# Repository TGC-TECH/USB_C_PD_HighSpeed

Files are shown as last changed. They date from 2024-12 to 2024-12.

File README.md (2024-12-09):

# USB_C_PD_HighSpeed
High Speed USB C PD Hub

This was submitted for the ECSE Senior Project at CWRU 
It was designed by myself(Toby Cowles), Carter Graefnitz  & Zach Brown

You are welcome to modify the design with credit. 
Design Files are provided in Altium Designer 

Before ordering look at the technical report.pdf
The design should in theory work but is untested and has some minor clearence issues on U6 and C32
The design was designed for the JLC0616H-7628 stackup 

NO WARRENTY IS PROVIDED, THIS IS  FOR EDUCATIONAL AND REFERENCE PURPOSES ONLY!

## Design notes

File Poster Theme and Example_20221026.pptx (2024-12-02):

## High Speed High Power USB C PD Hub

Zach Brown (EE) Toby Cowles (EE,CE) Carter Graefnitz (EE)

Instructor/Advisor Dr.Gregory Lee, PhD, (ECSE Case Western Reverse University)

Problem, Background & Context:
There is not a commercial USB hub available that is capable of supplying high power USB C PD and high speed data (10Gb/s+) on the same hub. Therefore we propose the design and manufacture of such a hub.
Similar existing solutions are all flawed :
Commercial Solutions
-USB C Hubs (no power)
-USB PD adapters (no data)
-Thunderbolt Docks
(bulky, expensive, unneeded features, limited ports)
Existing Projects
https://github.com/Jana-Marie/PD-Injector
(Clunky, violates USB Spec, but provided assurance that something like this could be done)

System Architecture & Tech Constraints:
1. Limited IC selection. There are few 10gb/s USB hub ICs on the market and none faster Making custom ICs/working with non-public ICs is out of scope of this project so we will be constrained by what is available.
2. Routing traces and manufacturing boards for high frequency data gets more difficult the higher the data speed, which could limit the CMs we can work with as well as impose limits on the design tools required.
3. Troubleshooting data lines may be difficult given that it would require an oscilloscope fast enough to keep up with a 10 Gb/s data speed.

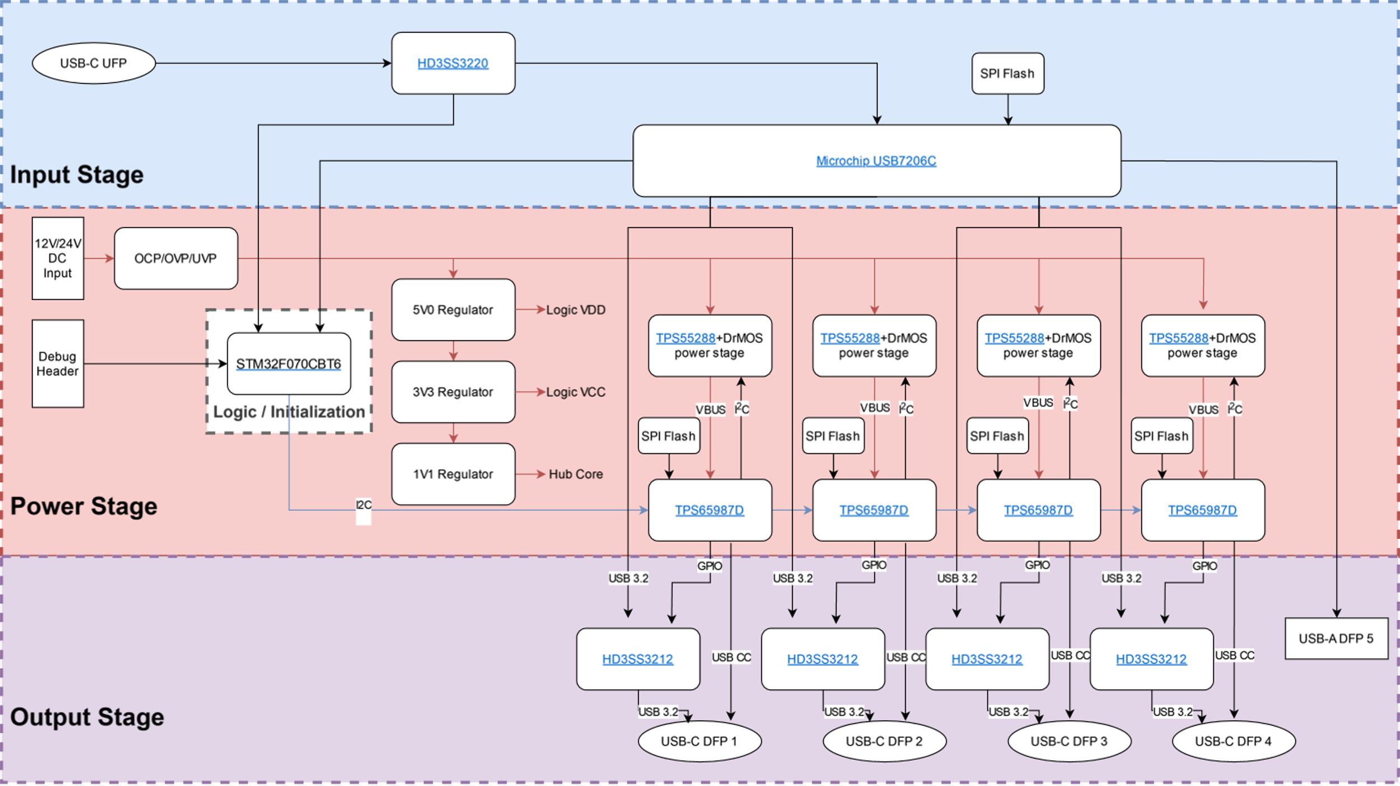
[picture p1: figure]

Schematic Capture:

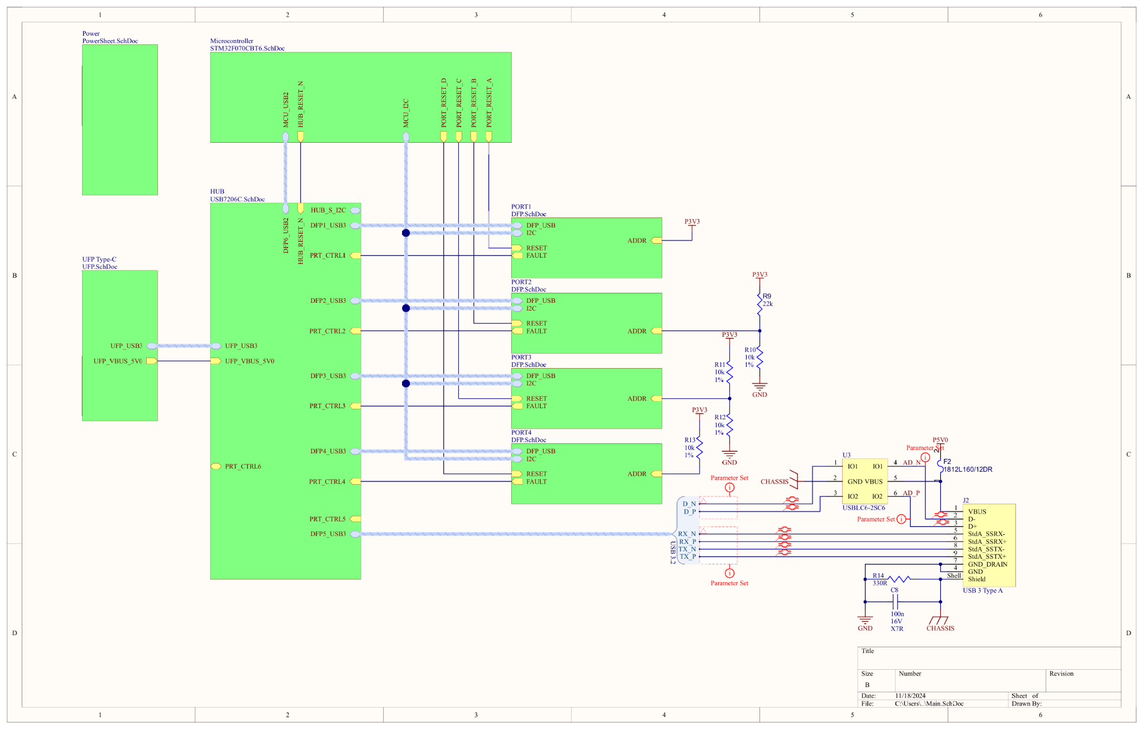
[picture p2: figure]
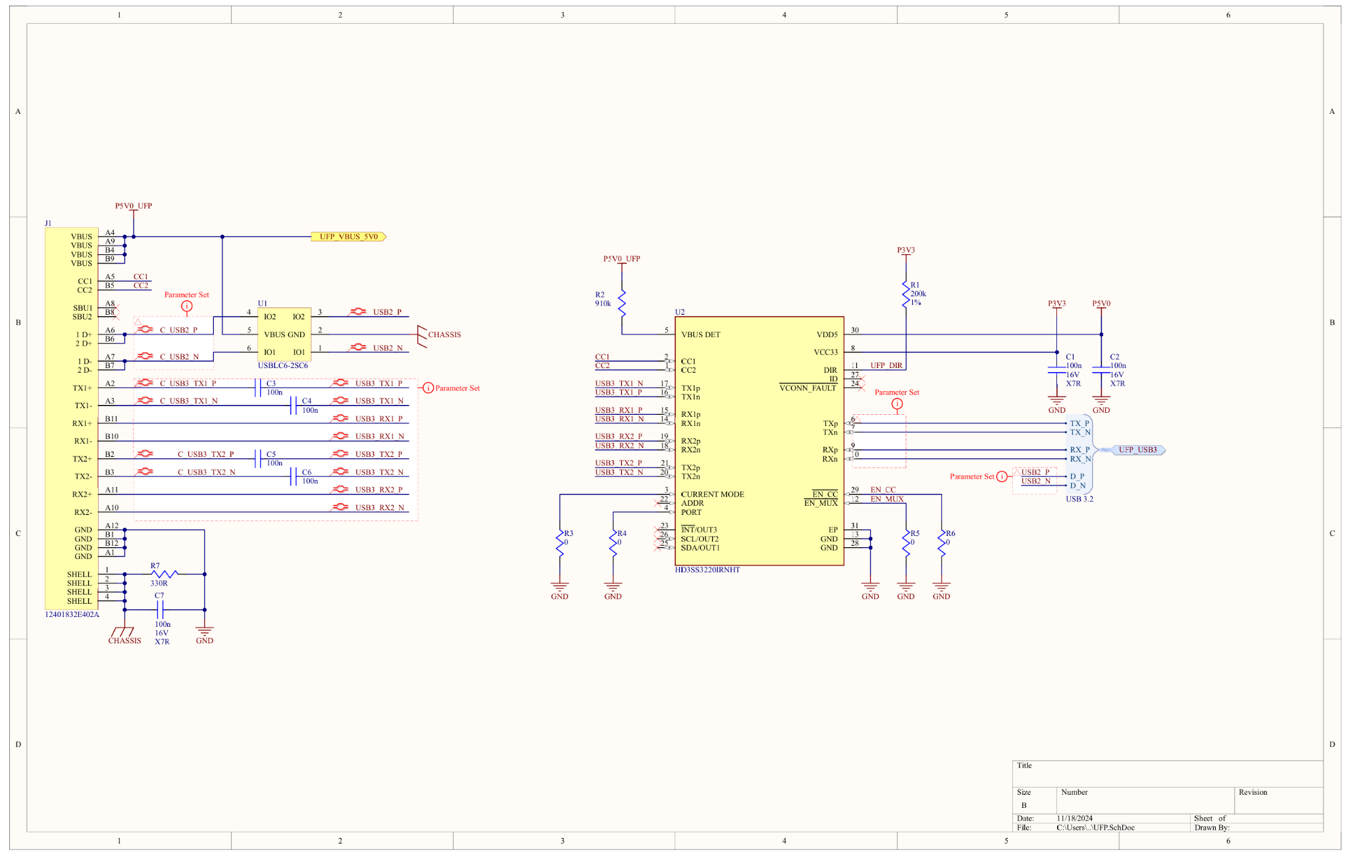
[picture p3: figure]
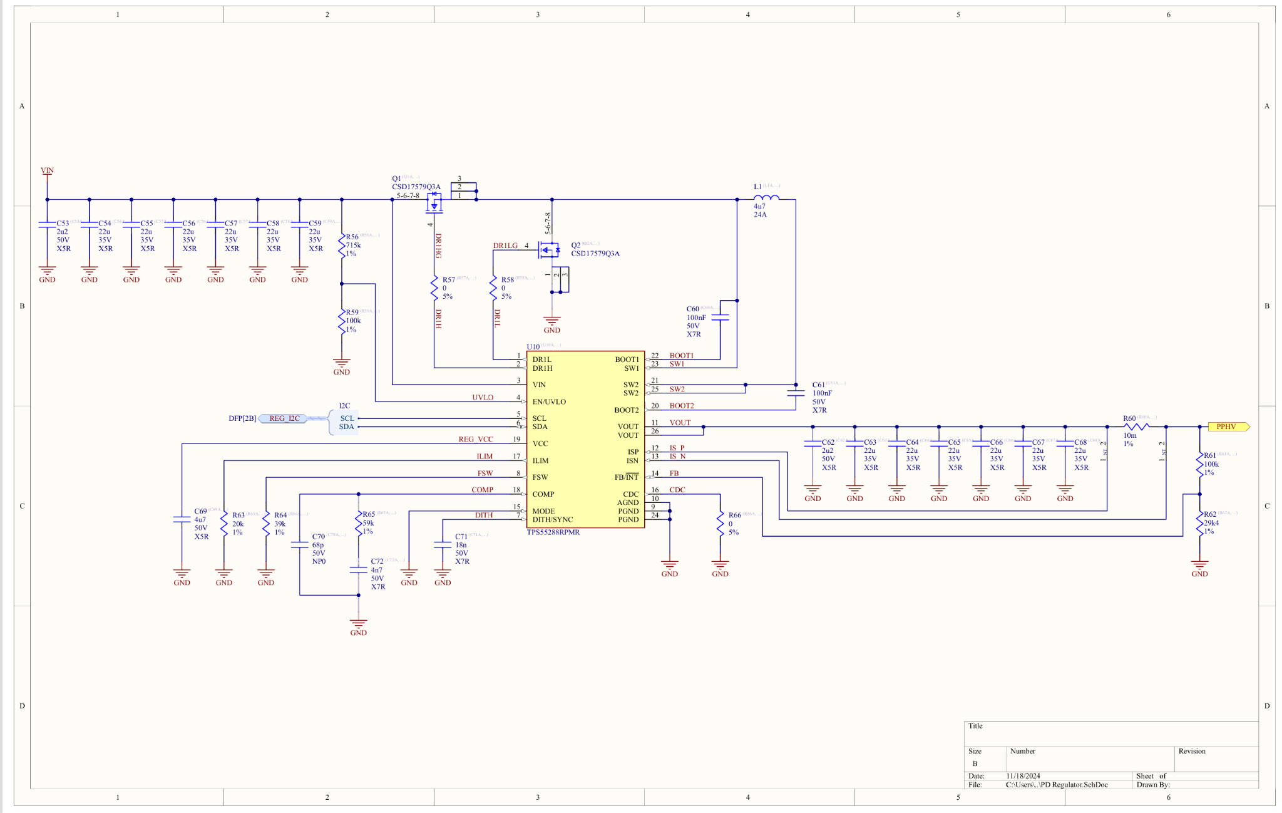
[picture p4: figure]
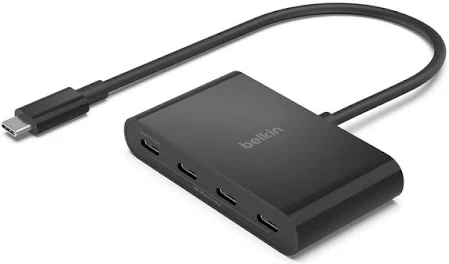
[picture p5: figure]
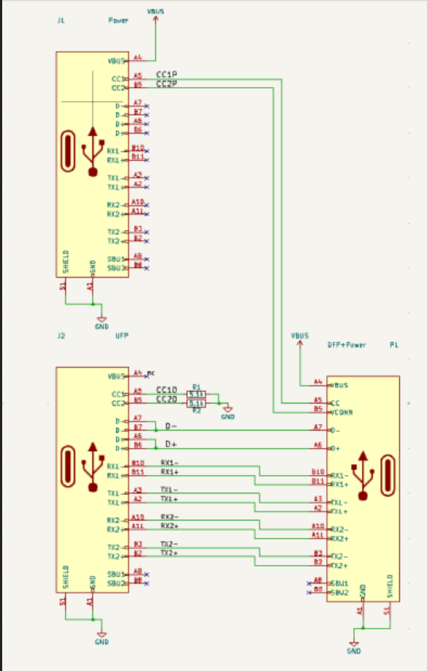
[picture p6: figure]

Jana Marie (github.com)

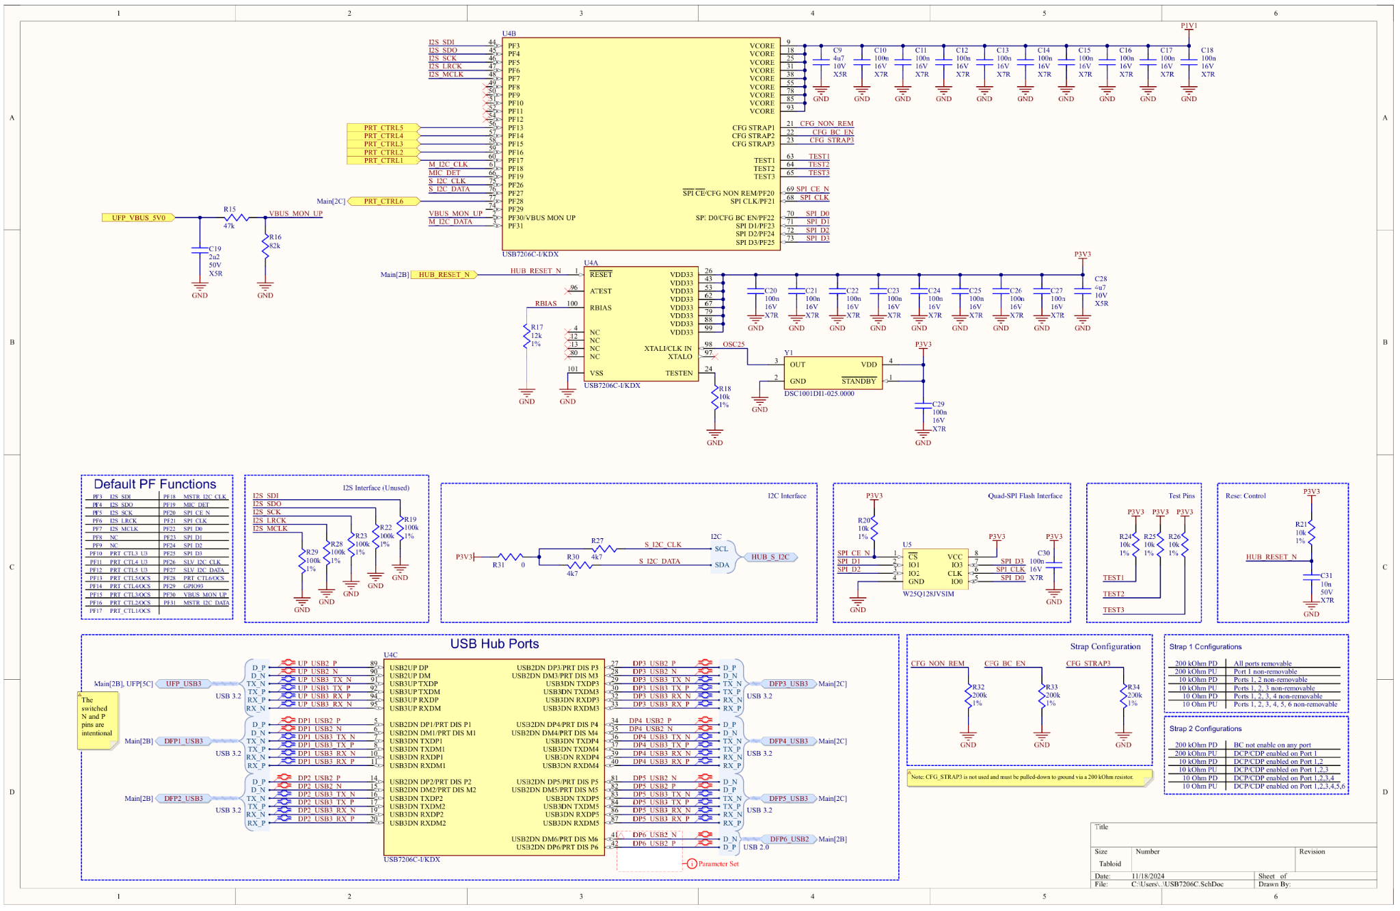
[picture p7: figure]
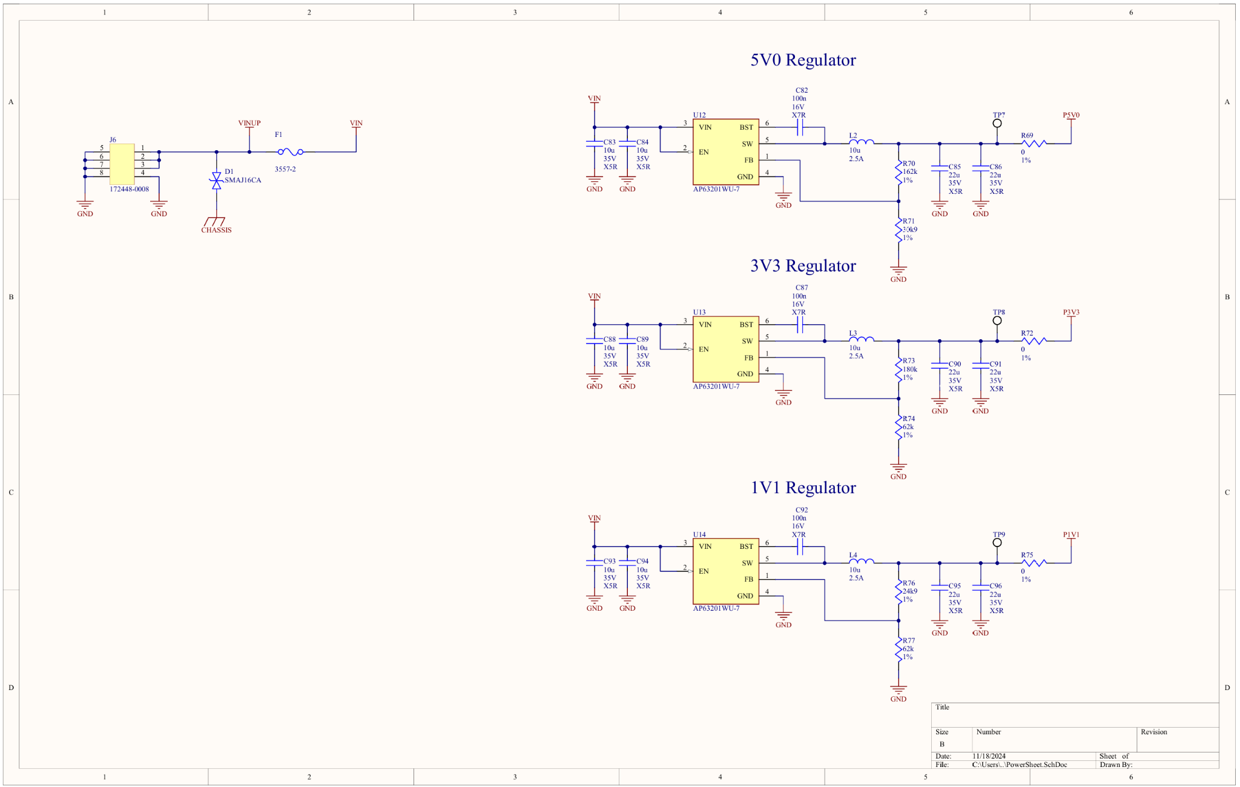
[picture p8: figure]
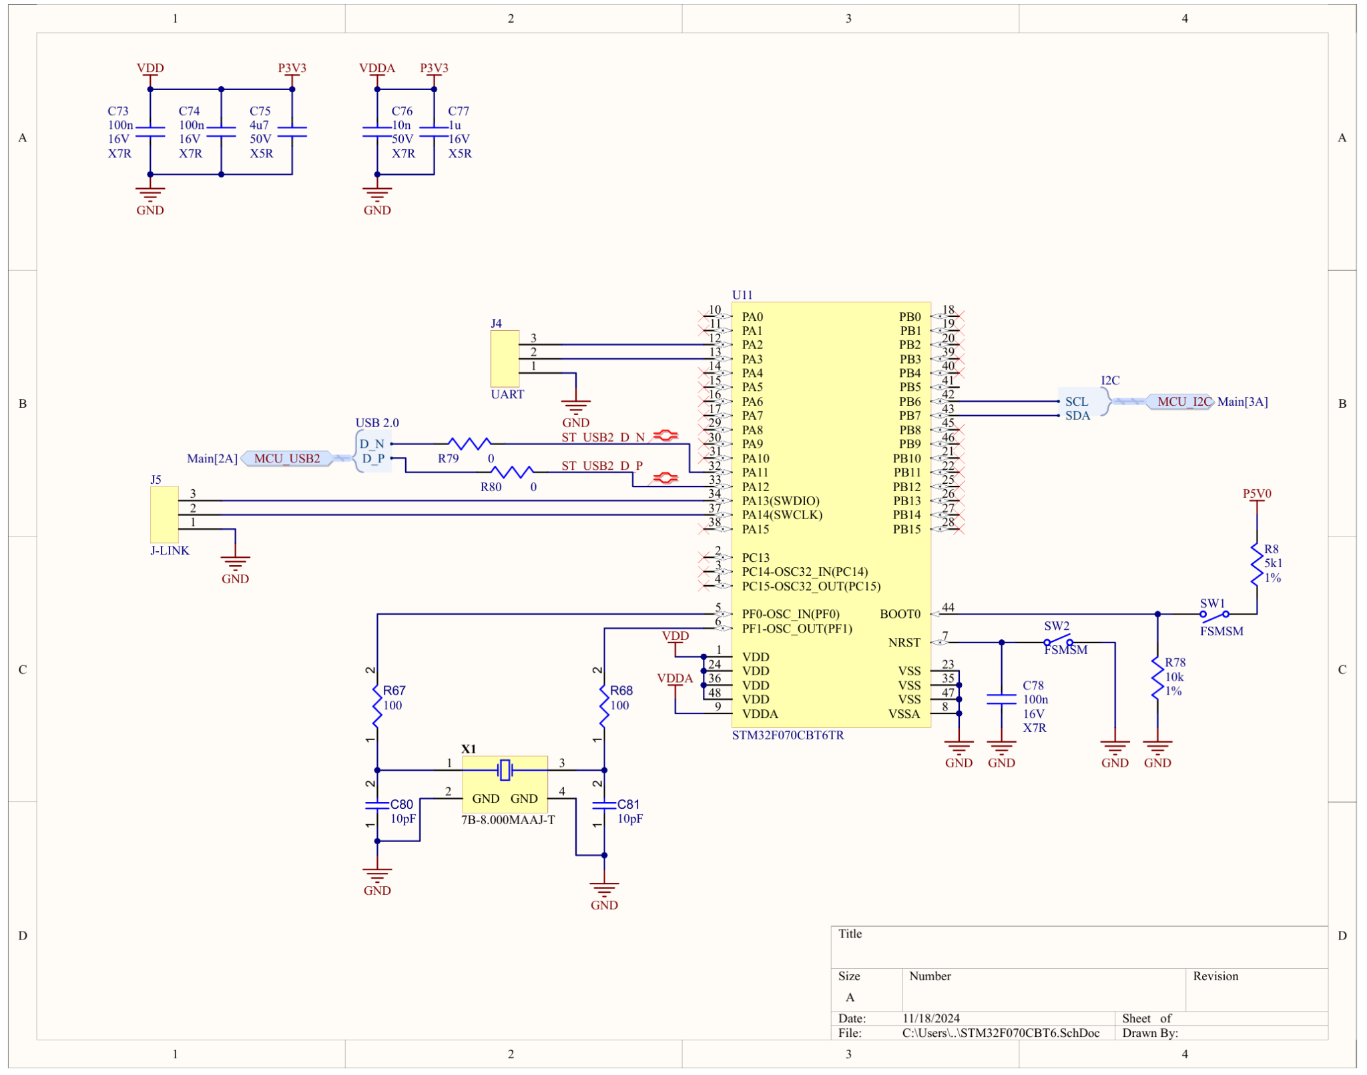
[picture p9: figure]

Schematic Capture was completed in Altium Designer.
We used a multi-sheet layout and sheet symbols to make the project efficient

Belkin.com

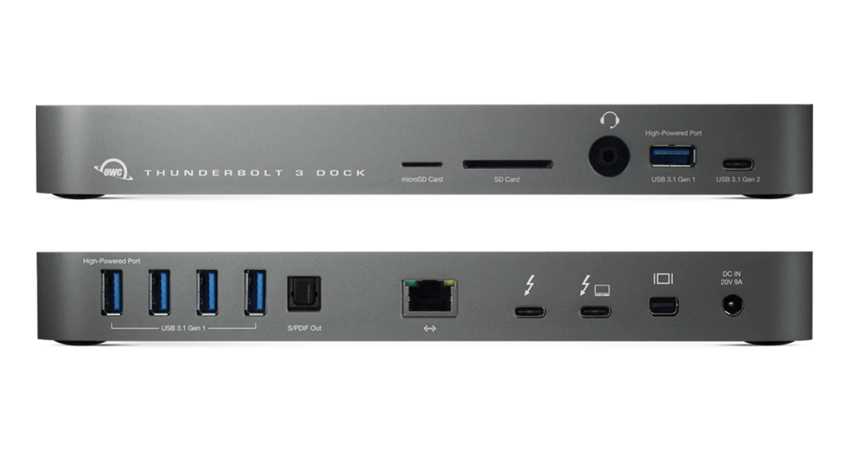
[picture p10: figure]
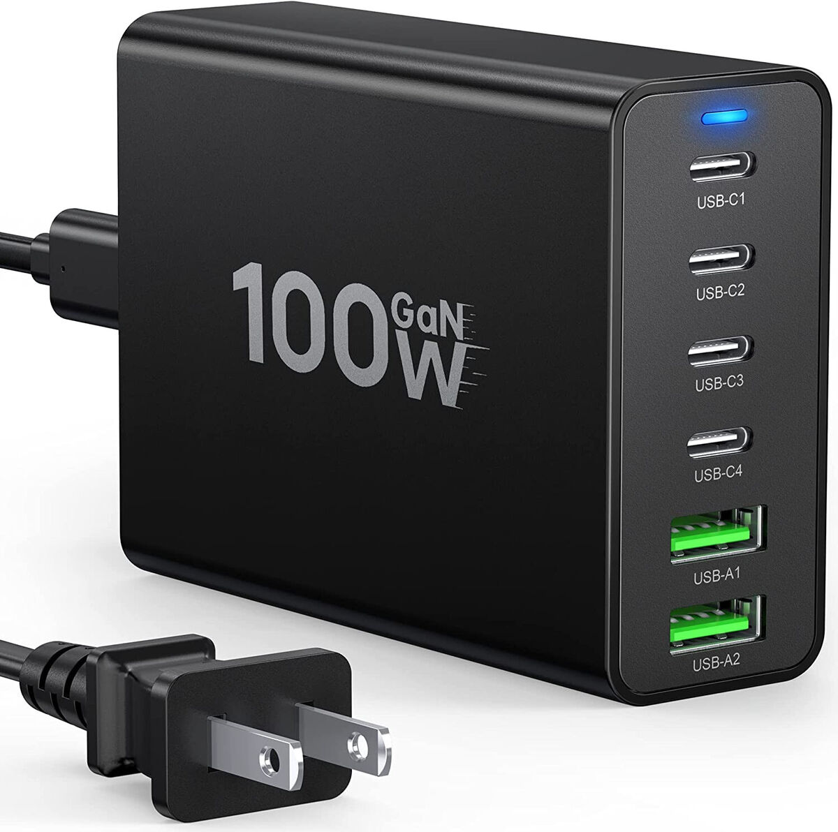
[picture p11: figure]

Amazon.com

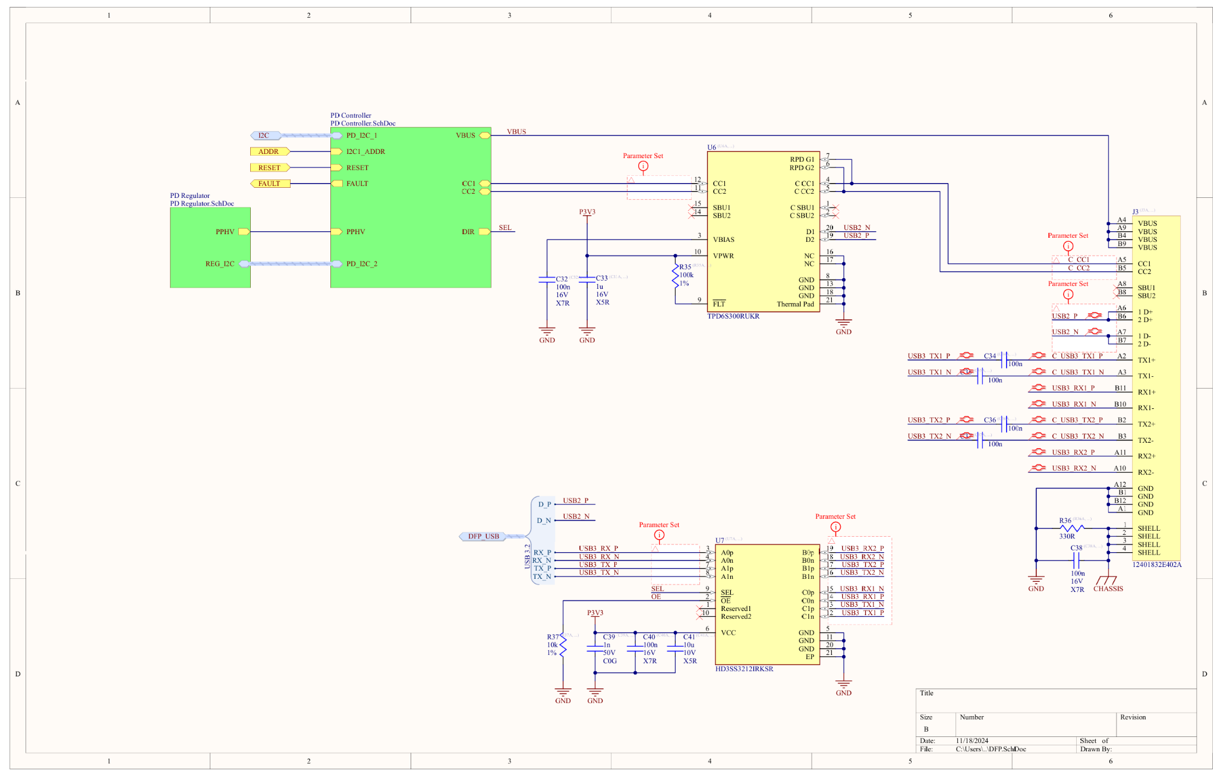
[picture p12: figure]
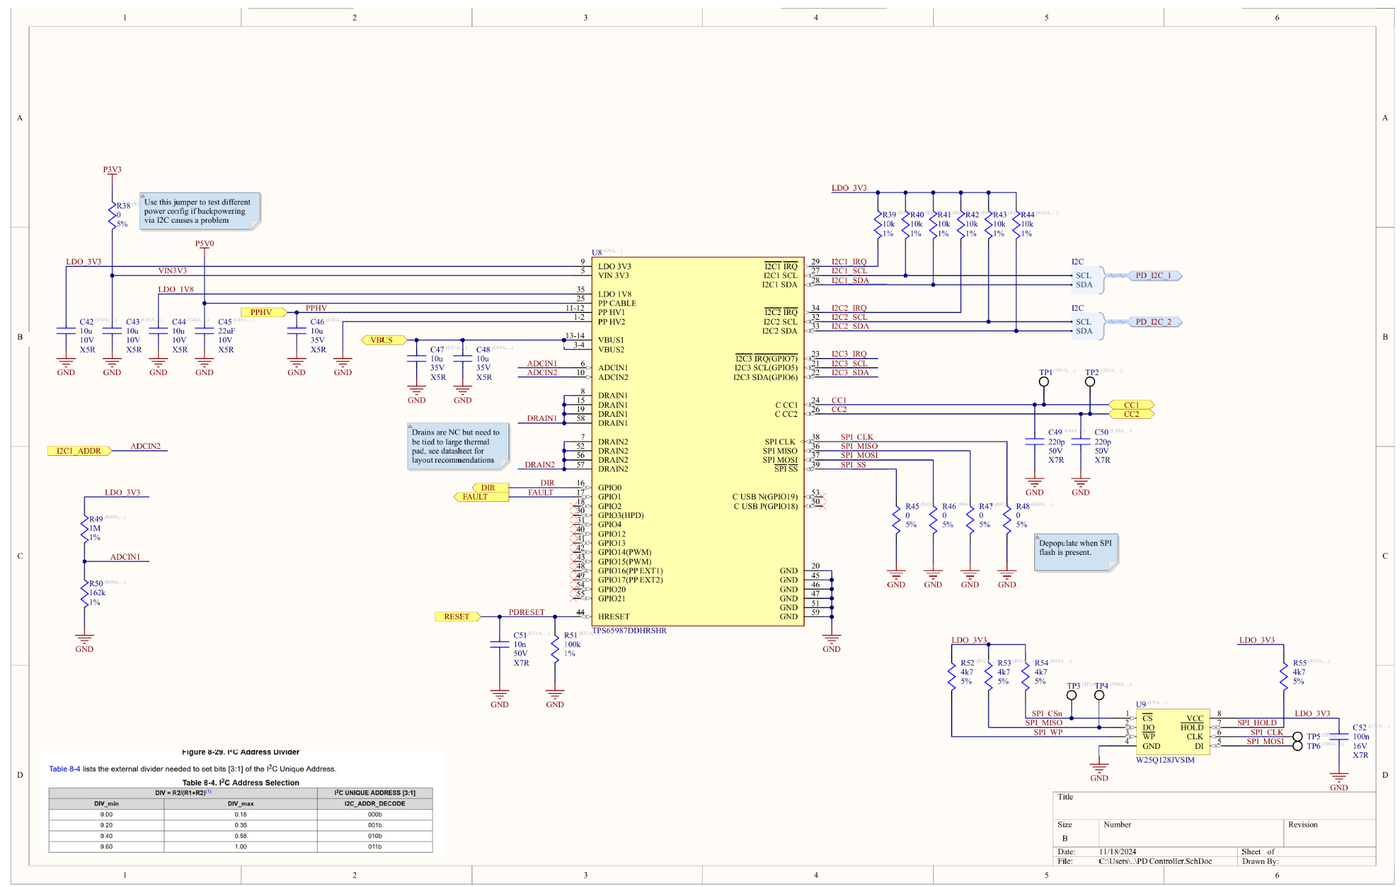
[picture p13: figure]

PCB Layout:
Project Management:

We laid out the board as a 6 layer board. We kept the high-speed signals on the outer layers to prioritize signal integrity and avoid issues with punch through. Each outer layer has a ground plane underneath it. The two inner layers are used for low-speed signals and power.

OWC.com

Manufacturing:
Results and Verification:

We designed our board with manufacturability in mind. Early on in the design process we identified our target CM [contract manufacturer] as JLC PCB. We chose JLC due to their extensive part library, competitive capabilities, fast turn times and low prices. We defined our board layer stack based on the JLC0616H-7628 stack up to meet our impedance requirements. All our parts included the JLC part number for ease of ordering.

In order to verify our board we ran DRC on the design.
DRC identified 95 possible violations.
After review it was determined 40 of these violations are nets in the CC class not meeting the defined rules for their target impedance due to space constraints, and should be able to be safely ignored.
25 of these are net antenna violations caused by TI provided footprints, and can also be ignored. The remaining 20 are small annular rings in the Amphenol provided footprints on the USB C connectors and can also be safely waived.

Copyright © 2024

Standards/References:
FCC Radio Devices Rule on Homebuilt Devices, 47 C.F.R § 15.23, 2021. [Online] Available: https://ecfr.federalregister.gov/current/title-47/chapter-I/subchapter-A/part-15. Accessed May 12, 2021.
Universal Serial Bus 3.2 Revision 1.1 Specification, USB-IF, USB 3.0 Promoter Group, June 2022. [Online]. Available: https://usb.org/document-library/usb-32-revision-11-june-2022
USB Power Delivery Specification Revision 3.2, Version 1.0, USB-IF, Oct. 2023. [Online]. Available: https://usb.org/document-library/usb-power-delivery
USB Type-C Cable and Connector Specification Release 2.3, USB-IF, Oct. 2023. [Online]. Available: https://usb.org/document-library/usb-type-cr-cable-and-connector-specification-release-23
I²C-bus specification and user manual, UM10204, NXP Semiconductors, Oct. 2021. [Online]. Available: https://www.nxp.com/docs/en/user-guide/UM10204.pdf
IPC, IPC-2141: Controlled Impedance Circuit Boards and High Speed Logic Design (IPC-2141A), Revision A. IPC, 2004.
Relevant Courses:
Acknowledgements:

Course | Description
ENGR 210 | Basic circuit and network theory, use of instrumentation
ECSE 245 | More advanced power circuitry
ECSE 309 | Covers high speed/high frequency signals. Impedance matching
ECSE 344 | More advanced power circuitry
ECSE 371 | Applied circuit design
ECSE 303 | Firmware development

Thank you to Altium for providing student licenses. Thank you to Dr.Lee for being our advisor and his lab for supporting this project financially.

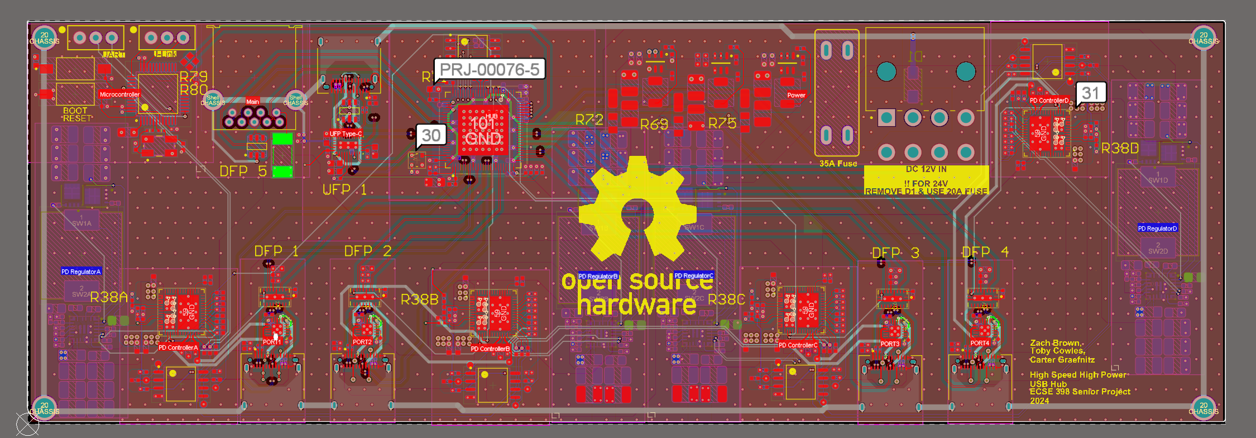
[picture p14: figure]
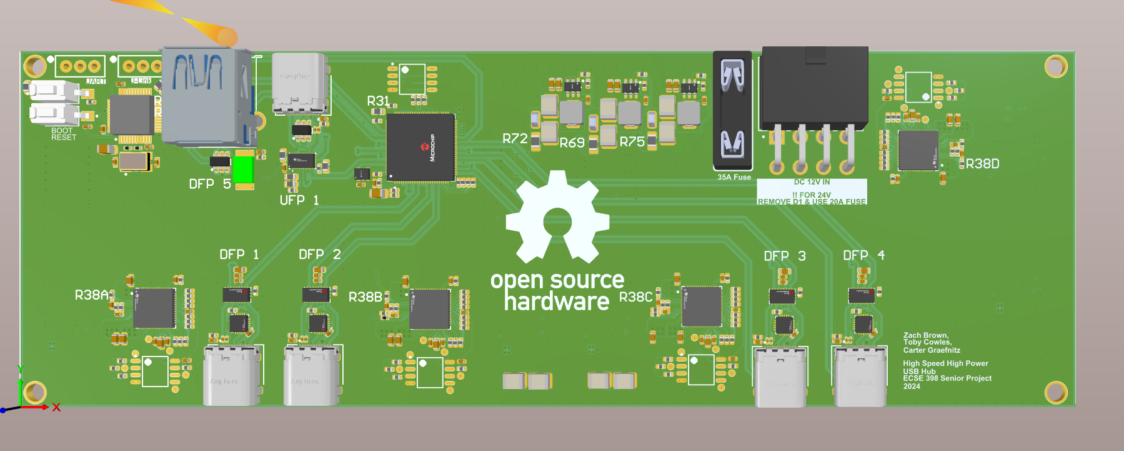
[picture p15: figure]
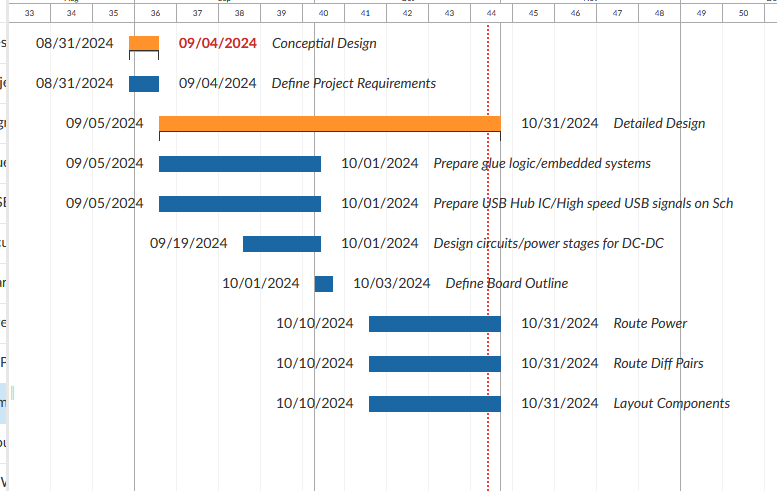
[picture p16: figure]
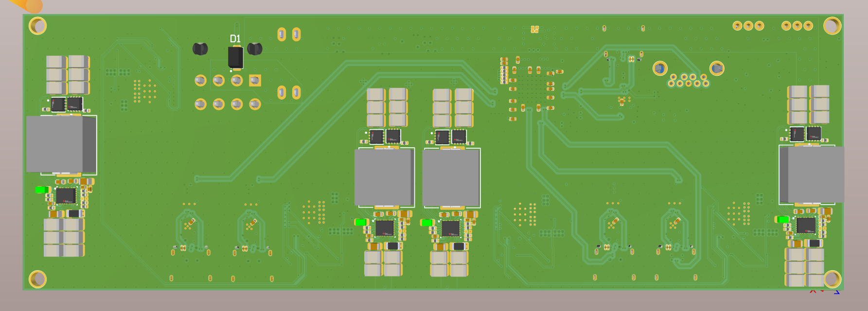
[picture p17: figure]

In order to ensure the project was completed on time we used project management strategies to divide and plan out the work including a detailed project plan document and a Gantt Chart. We also did multiple design reviews throughout.

Presented: December 6th, 2024

ECSE 398

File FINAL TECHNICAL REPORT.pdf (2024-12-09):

Zach Brown <zeb12@case.edu> | Toby Cowles <tgc21@case.edu> | Carter Graefnitz <cmg194@case.edu>

Technical Advisor: Dr. Gregory Lee, Professor of Electrical Engineering, Case Western Reserve University
Instructor: Dr. Gregory Lee

Submitted for ECSE 398 in partial fulfillment for the degree of Bachelor of Science of Electrical Engineering

Case Western Reserve University

Fall 2024

All students in this course are expected to adhere to University standards of academic integrity. Cheating, plagiarism, misrepresentation, and other forms of academic dishonesty will not be tolerated. This includes, but is not limited to, consulting with another person during an exam, turning in written work that was prepared by someone other than you, making minor modifications to the work of someone else and turning it in as your own, or engaging in misrepresentation in seeking a postponement or extension. Ignorance will not be accepted as an excuse. If you are not sure whether something you plan to submit would be considered either cheating or plagiarism, it is your responsibility to ask for clarification. For complete information, please go to https://students.case.edu/community/conduct/aiboard/policy.html.

The individual(s) submitting this document affirm compliance with the above statement

__________________ | __________________ | __________________

This document details the design and development of a high-speed, high-power USB-C Power Delivery (PD) hub. The primary objective of this project was to create a USB hub capable of delivering high power (up to 100W per port) and high-speed data (10Gb/s) simultaneously, overcoming limitations found in existing commercial solutions.

Design and Implementation:

The project involved selecting appropriate Integrated Circuits (ICs) to meet speed and power requirements, designing a block diagram, and capturing a schematic for the hub. The design was then laid out onto a multilayer PCB, which was reviewed and validated by stakeholders.

Benefits:

The proposed hub offers a highly integrated solution that leverages USB-C and USB 3.2 Gen 2 capabilities without unnecessary features, reducing cost and complexity. It provides a viable alternative to existing solutions which either lack power delivery or data transfer capabilities.

Technical Constraints:

Challenges included limited IC selection for high-speed USB hubs and the complexity of routing high-frequency data traces. The design adhered to USB-IF and IPC standards to ensure signal integrity and manufacturability.

Results and Verification

The project successfully produced a PCB design that integrated all target functionalities and met design rule checks. Some issues with component availability and clearance were noted, but the design was manufactured successfully with minor adjustments.

Budget and Project Management

The project was managed using a Gantt chart and communication tools, with a budget of $636.01 for five assembled units. The project remained within our initial estimated budget, demonstrating effective cost management.

Conclusion

The USB-C PD hub project achieved its primary objectives, providing a functional and efficient design. Further work is needed to complete assembly and functional validation. The project represents a significant step forward in developing versatile and high-performance USB hubs.

Academic Integrity Policy | 1
Executive Summary | 1
Table of Contents | 2
Problem Statement: | 2
Approach: | 2
Benefits: | 3
Competition: | 3
Purpose, Goals & Objectives: | 3
Requirements: | 3
Success Criteria | 4
Design Criteria: | 4
Functional Criteria: | 4
Technical Constraints | 5
Standards | 5
FCC: | 5
USB-IF: | 6
IPC: | 6
Background and Context: | 7
Project Overview | 8
Design Tools | 9
Schematic Capture | 9
PCB | 10
Assembly/Fabrication | 10
Design Changes: | 11
Verification & Results | 12
Verification: Statement of Success Criteria #1-3 | 13
Methods | 13
Results | 13
Analysis/Conclusion | 13
Project Management | 14
Relevant Courses | 14
References | 15
Appendix A: An Appendix | 15

There is not a commercial USB hub available that is capable of supplying high power USB C PD and high speed data (10Gb/s+) on the same hub. Therefore we propose the design and manufacture of such a hub.

Our recommended approach is as follows:
First we will research the relevant USB-IF specifications and select ICs capable of implementing a hub that will support USB 3.2 gen 2, as well as 100W USB PD.
We will design a block diagram including all of these ICs in order to better understand the system level approach. Next we will capture a schematic of the hub that implements the recommended ICs, and review it with the stakeholders as well as other electrical engineers. Afterwards we will lay out the schematic onto a multilayer PCB, and have the layout reviewed by stakeholders and other electrical engineers.
Finally we will have the board fabricated and assembled by a Contract Manufacturer (CM), and shipped to CWRU for bring-up and validation.

The benefit of our solution compared to commercial solutions is that our solution takes full advantage of the capabilities offered by USB C and USB 3.2 Gen 2 for data and power without any unnecessary features that would increase cost and complexity with no benefit for many applications. The specific commercial competition can be broadly categorized as falling into the following categories, each with a specific downfall compared to our product.

- USB Hubs: Can’t carry power beyond the standard 5V 1A of USB 3
- USB C PD Multiport Chargers: Can’t carry data
- Thunderbolt/USB Docks: Complicated, expensive, limited number of PD ports compared to other ports
Additionally our design approach offers the benefit of a highly integrated and polished solution capable of supporting this niche functionality, and we have IP for boards that can be used to order more boards as needed with ease, and can be tweaked or expanded if required in the future.
Requirement type: | Min Spec: | Notes

Speed | 10GB/s (USB 3.2 Gen 2)
Power output | 100w per port USB-C PD at 5, 9, 15, and 20V.
Power input | 12V/24V DC, 400w | We wanted to ensure our hub could operate across a range of input voltages to allow for multiple power supply battery configurations
Number of ports | 4 DFPs, 1 UFP
Size | <160mm x 160mm> | This is a general guideline and note a hard requirement

Table 1. Design requirements.

The design will be considered successfully if it:
Criterion 1. | A completed PCB design is produced
Criterion 1.1. | The PCB integrates all target functionality
Criterion 1.2. | The PCB design can be exported as a gerber design for assembly
Criterion 2. | The board completes a DRC with no serious violations
Criterion 2.1. | All trace widths are within manufacturer capabilities
Criterion 2.2. | All high speed traces meet impedance targets 1
Criterion 2.3. | All components do not violate pad to pad or courtyard clearances
Criterion 2.4. | No traces or components violate board edge clearances
Criterion 3. | The design passes the manufacturer DFM
Criterion 3.1. | No issues that prevent manufacturability are present in the PCB
routing

1 High speed differential pairs must be perfectly impedance matched to 90 ohms; the single-ended configuration channel signals for USB-C were also impedance matched to 50 ohms.

Criterion 3.2. All components can be assembled successfully by our CM

The project will be considered to be successful if the finished module:

Criterion 1. | Establishes successful USB data and PD links to a variety of devices.
Criterion 2. | Meets the relevant test assertions laid out in the following test
specifications in addition to any other documents we may find useful by USB-IF:

Criterion 2.1. USB Type-C and Power Delivery Source Power Requirements Test Specification (https://www.usb.org/sites/default/files/USB-C%20Source%20Power%20Test%20Specification%202021%2005%2024.pdf)

Criterion 2.2. | USB 3.2 Link Layer Test Specification (https://www.usb.org/sites/default/files/USB%203%202%20Link%20Layer%20Test%20Specification%202024%2003%2003.pdf)
Criterion 2.3. | USB Type-C Functional Test Specification (https://www.usb.org/sites/default/files/USB%20Type%20C%20Functional%20Test%20Specification%202024%2003%2003.pdf)
Criterion 3. | Stays within a safe temperature range
Criterion 3.1. | All ICs and switching components should have a surface
temperature of less than 80C under fall load

Criterion 3.2. All user accessible surfaces should have a surface temperature of under 55C

Criterion 4. Provides a viable alternative to commercial USB PD + data solutions

Early on in the project we identified some technical constraints that would drive some elements of the design.
TC 1. Limited IC selection. There are few 10gb/s USB hub ICs on the market and none faster Making custom ICs/working with non-public ICs is out of scope of this project so we will be constrained by what is available.

TC 1.1. We will choose ICs that are capable of meeting our speed target of >=10gb/s

TC 1.2. | We will choose ICs that are easily available through our contract CM
TC 2. | Routing traces and manufacturing boards for high frequency data gets more
difficult the higher the data speed, which could limit the CMs we can work with as well as impose limits on the design tools required.

TC 2.1. Stackup will follow Microchip Inc. and USB IF recommendations for weave to ensure good signal integrity. This includes selecting a thin dielectric between layer 1 and ground, selecting at least 1 oz./ft² copper
weight, and selecting a substrate with low tangent losses and a uniform dielectric constant.
TC 2.2. | USB differential pairs will be impedance controlled to 90 ohm ± 7 ohms
TC 2.3. | USB diff pairs will be referenced to a ground plane immediately below or
above them.
TC 2.4. | USB CC lines will be impedance controlled to 50 ohm ± 5 ohms
TC 3. | The ICs we choose should be able to work together within the USB C, USB 3.2,
and USB PD specifications/standards.
TC 3.1. | Only one IC may communicate with the downstream device
TC 3.2. | USB 3.2 data should be MUXed prior to the USB C port to allow
reversibility based on the direction detected by the CC lines

TC 3.3. The full USB PD voltage range (5-20V) should be supported based on negotiation over the CC lines

Understanding these technical constraints informed our design approach, we knew that choosing the right ICs was the foundation the rest of the project would depend on. We also knew that in order to achieve success we needed to be able to design and manufacture a board that could carry the required data speeds. We also knew that in order to choose the right ICs we needed to understand the standards.

Using the definitions provided in 47 CFR part 15 subsection 3 of the FCC’s rules, we can classify our device as both a “digital device” and an “unintentional radiator.” The frequency of the digital clock signals utilized in our device operate above 9kHz, requiring it to be classified as a “digital device” under paragraph (k). Additionally, because our device transmits radio frequency signals via copper traces without the intention “to emit RF energy by radiation or induction,” it falls under paragraph (z), classifying it as an “unintentional radiator” [1].

[1] FCC Radio Devices Rule on Definitions, 47 C.F.R § 15.3, 2024. [Online] Available: https://www.ecfr.gov/current/title-47/chapter-I/subchapter-A/part-15/subpart-A/section-15.3. (https://www.ecfr.gov/current/title-47/chapter-I/subchapter-A/part-15/subpart-A/section-15.3) Accessed November 20, 2024.

Although this project was inspired by a missing commercial solution in mind, our intent for the design and manufacturing is largely developmental and we do not intend to sell or market the device. We do not expect this design to be widely distributed and have only ordered 5 devices for manufacturing. This device was designed as part of an academic exercise with the expectation that it will only be used within a controlled laboratory environment for further academic research. For these reasons, this device falls under subsection 23 [2], allowing it to be classified as a home-built device, exempting it from the majority of regulations applied to the classifications in subsection 3 paragraphs (k) and (z) [1] since we have employed the best engineering practices to our knowledge as required by subsection 23 [2].

[2] FCC Radio Devices Rule on Homebuilt Devices, 47 C.F.R § 15.23, 2024. [Online] Available: https://www.ecfr.gov/current/title-47/chapter-I/subchapter-A/part-15/subpart-A/section-15.23. Accessed November 20, 2024.

Home-built devices, however, must still comply with the conditions of 47 CFR 15.5 [3]. Since our device classifies as an unintentional radiator, subsection 5 requires any user of our device to cease operations upon notification of harmful interference due to the device’s radio frequency emissions [3].

[3] FCC Radio Devices Rule on General Conditions of Operation, 47 C.F.R § 15.5, 2024. [Online] Available: https://www.ecfr.gov/current/title-47/chapter-I/subchapter-A/part-15/subpart-A/section-15.5. Accessed November 20, 2024.

The PHY implementation in the PCB layout was implemented following recommendations provided in several USB-IF standards.

[4] Universal Serial Bus 3.2 Revision 1.1 Specification, USB-IF, June 2022. [Online]. Available: https://usb.org/document-library/usb-32-revision-11-june-2022. (https://usb.org/document-library/usb-32-revision-11-june-2022) Accessed November 20, 2024.

This revision of the USB 3.2 Specification covers architecture, protocols, and data transfer models, focusing on the enhanced SuperSpeed bus architecture, error handling, power management, and backward compatibility with USB 2.0. The specification outlines detailed requirements for device manufacturers to ensure compliance and interoperability within the USB ecosystem, including mechanical, physical, and electrical layer standards, as well as packet transmission and error recovery mechanisms. Particularly relevant for our project is the way SuperSpeedPlus hubs exhibit distinct behaviors compared to previous types of USB hubs. SuperSpeedPlus hubs, operating at Gen 1x2 speeds or beyond, such as the gen2 hub used in this project, utilize a store-and-forward model, enabling the reception of multiple packets before retransmitting. This design supports more efficient packet scheduling across multiple devices. Additionally, both hub types manage transitions from low-power states and preserve packet order during data transmission.

[5] USB Power Delivery Specification Revision 3.2, USB-IF, Oct. 2023. [Online]. Available: https://usb.org/document-library/usb-power-delivery. (https://usb.org/document-library/usb-power-delivery) Accessed November 20, 2024.

This revision of the USB Power Delivery Specification provides detailed descriptions of power modes and the contract negotiation process in the USB Power Delivery Specification. Describes the system operates in different power modes, such as Standard Power Range (SPR) and Extended Power Range (EPR), each requiring specific contract negotiation. For SPR the fixed voltage levels include 5V, 9V, 15V, and 20V. The associated current levels vary, with maximum currents of up to 3A for most voltage levels. In specific cases, a 5A cable can allow for higher current delivery. The programmable power supply (PPS) mode for SPR mode supports voltage levels ranging from 5V to 21V with similar current levels depending on the power profile (15W, 27W, 45W, 60W, 100W). In an explicit contract negotiation, the source advertises its power capabilities, and the sink evaluates and requests the appropriate power levels, followed by the source acknowledging the request and adjusting the power accordingly. This contract negotiation is essential for ensuring optimal power delivery. Furthermore, implicit contracts are used temporarily, such as during power role swaps, but they are immediately followed by explicit contract renegotiation

[6] USB Type-C Cable and Connector Specification Release 2.3, USB-IF, Oct. 2023. [Online]. Available: https://usb.org/document-library/usb-type-cr-cable-and-connector-specification-release-23. Accessed November 20, 2024.

This USB Type-C specification explains in detail the role and capabilities of both the USB Type-C cable and receptacle. Our interest will be in understanding the configuration channel (CC) and its role in determining plug orientation, sink/source power roles, and UFP/DFP data roles. Particularly important to our project, the CC is where contract negotiations take place for USB PD implementation and the determination of Vconn. This standard also points out the differences between USB Type-C cables, noting that cables can have differing capabilities relating to the supported version of USB, cable length, current ratings, and supported PD ranges. To meet the USB 3.2 Gen 2 and 100W PD capabilities of our hub, a CC3G2-5 Type-C cable or higher must be used.

[7] IPC-2221: Generic Standard on Printed Board Design (IPC-2221B), Revision B. IPC, 2012.

IPC-2221 is the industry standard for the design and layout of printed circuit boards. It is a massive document that details everything from the selection of materials and foils for a PCB design to the differences in topology of the solder on a HASL leaded versus lead free pad. 2221 is applicable to our project mostly because we are developing a sophisticated, high speed and high power PCB. 2221 will assist us in ensuring that our board is able to meet the demanding requirements of our project while still being meeting manufacturability constraints and remaining affordable.

[8] IPC-6012: Qualification and Performance Specification for Rigid Printed Boards (IPC-6012C), Revision C. IPC, 2010.

IPC-6012 goes over the criteria for the design process, materials, testing and finally acceptance of PCBs to ensure reliability and quality. 6012 covers electrical integrity, durability, environmental stresses, and general performance. We selected 6012 specifically because of the demanding environment that our final hardware will face, and its need to be able to withstand high vibration environments and specific shock load cases.

[9] IPC-2141: Controlled Impedance Circuit Boards and High Speed Logic Design (IPC-2141A), Revision A. IPC, 2004.

IPC-2141 goes over selecting trace geometry to meet the demands of high speed and controlled impedance boards. It focuses on microstrip and stripline waveguides, as well as outlining guidelines for developing functional and manufacturable high speed PCBAs. We selected IPC-2141 as our design is very high speed, and a majority of the traces on our board will be serving as transmission lines that need to be impedance and length matched.

The design process for our hub started with our conceptual design phase where we researched different options for components. Using this initial set of components, we drew out a system block diagram.

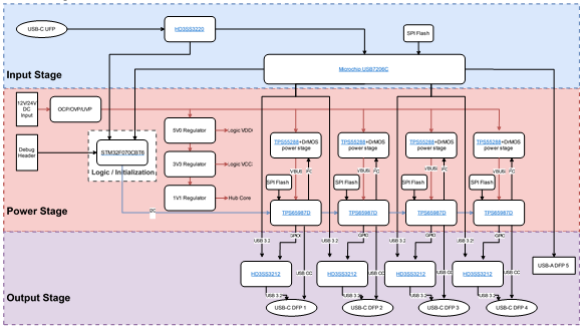
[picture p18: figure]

Figure 1. Architectural block diagram.

We ultimately selected the Microchip USB7206C as our main hub IC for several reasons. First, Microchip was one of the few companies offering publicly available USB 3.2 Gen 2 hub ICs. Second, this IC was well-documented and featured five USB 3.2 Gen 2 downstream facing ports (DFPs) and one USB 2.0 DFP. Four of the USB 3.2 DFPs were connected to Texas Instruments (TI) HD3SS3212 MUX ICs. These MUXes were chosen because they supported USB 3.2 Gen 2 speeds and did not rely on CC lines for direction detection. Instead, direction detection could be set via an external GPIO.To control the MUXes' directionality and handle power delivery (PD) negotiation on the CC lines, we used the TI TPS65987D. This highly versatile IC can directly control the MUXes through GPIO and manage the TI TPS55288 digital buck/boost converter over I²C. As a result, our hub is capable of functioning as a fully integrated hardware device compliant with the USB specification. However, to add flexibility, we also included an STM32F070CBT6 microcontroller (MCU). This MCU enables configuration and bootstrapping of the other ICs as needed.

One of the most critical components of the hub project is the PD subsystem. This subsystem is responsible for listening for a power delivery (PD) request over the CC pins, negotiating a PD contract with the downstream device, telling our digital buck-boost converters to go to this set voltage, and finally closing the load switches to connect the converter to the downstream port. There are a few tricky pieces to this task. First, the regulators must be able to provide anywhere from 5 volts to 21 volts at up to 5 amps. With an input voltage of 12 volts, we need a solution capable of either “bucking” the voltage down from 12V to 5V, or “boosting” the voltage up to 21V. The solution we ended up with is a buck-boost controller from TI, the TPS55288. This controller is a 4-switch buck-boost converter with an I²C interface that allows our PD port controller, the TPS65987D, to pass the voltage requested by the downstream port to the regulator. The TPS65987D is responsible for ensuring that the output voltage and current of the regulator are within the ranges specified by the contract, and will open its load switches in the case that an overcurrent or incorrect output voltage is detected.

We also simulated the hardware design of the buck-boost converter using TI’s Webench power designer. The plots below show some key performance metrics about the regulator design.

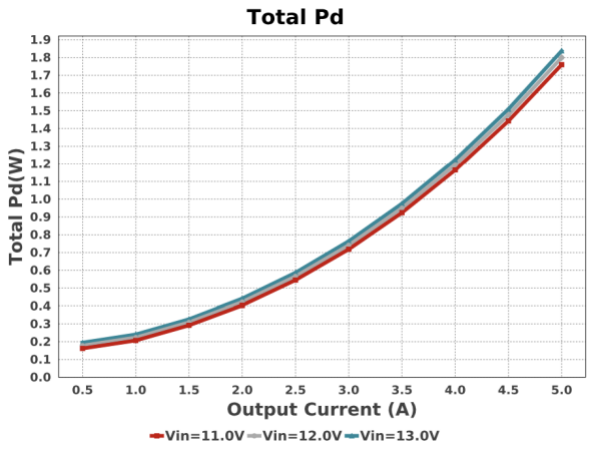
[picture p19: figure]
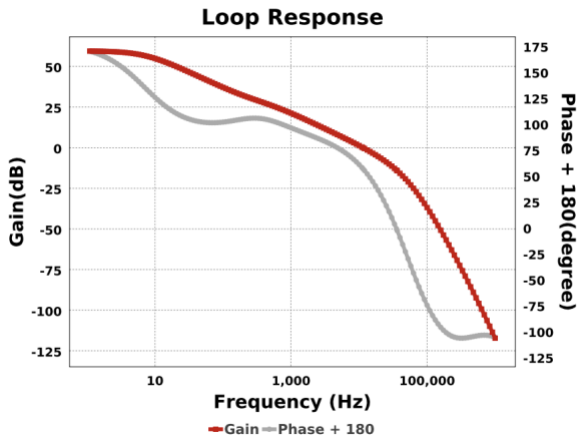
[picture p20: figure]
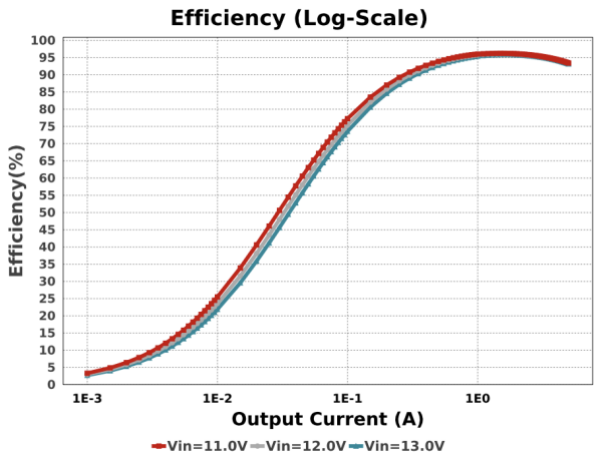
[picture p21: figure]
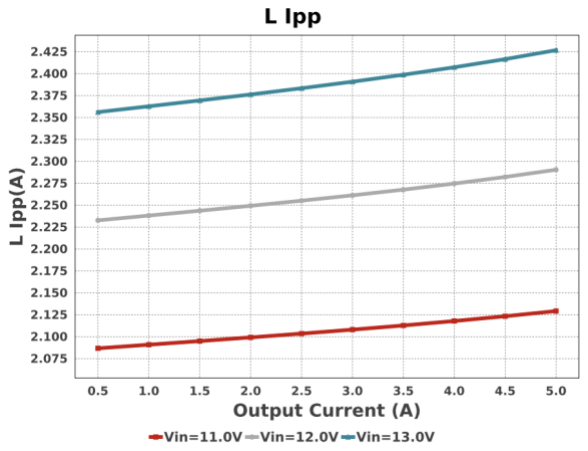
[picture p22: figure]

Figure 2. Closed loop response, total power dissipation, efficiency, and inductor current of the regulator.

We evaluated multiple different EDA (Electronic design automation) tools to complete our PCB design, we were initially planning on using KiCAD, as it is free, powerful, and fairly intuitive, however we ultimately chose to complete this project in Altium designer due to its superior routing capabilities for impedance controlled traces as well as it’s built in collaborative version control system (Altium 365), it’s support for multichannel designs and our ability to access free student licenses.

We completed the schematic capture using Altium’s multi channel design feature, this allowed us to design major blocks of our design on separate sheets which we could then turn into sheet symbols to integrate together. Thumbnails of the schematic sheets are attached here to provide an overview of the design structure. Full sheets are available in the appendix.

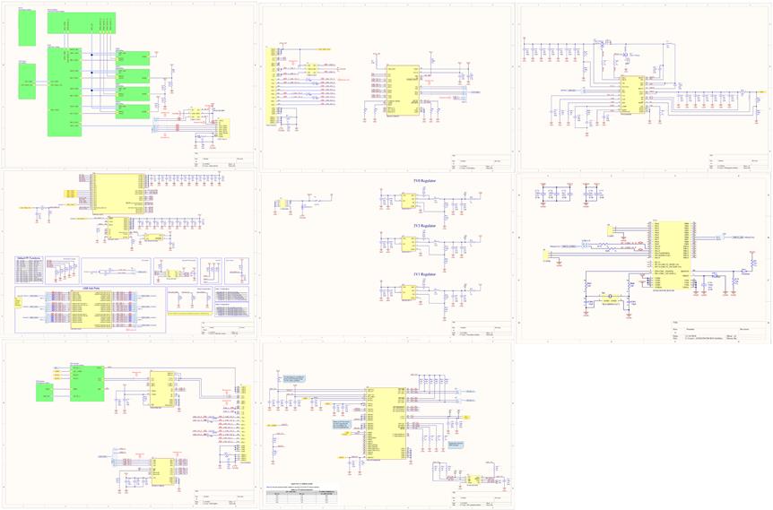
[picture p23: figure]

Figure 3. All schematic sheets.

After schematic capture we were able to import the netlist into a PCB document. We completed the initial layout of each ‘room’ or block of the multichannel design which could then be replicated out into the other rooms and laid out onto the board. We routed high speed data on the front and back with power and low speed data on layers 3 and 4. Layers 2 and 5 were both ground planes to provide a good ground reference to the whole board. We used via stitching at the end to ensure our ground was equipotential throughout. Our high speed traces were routed using net classes to ensure they met impedance and length requirements.

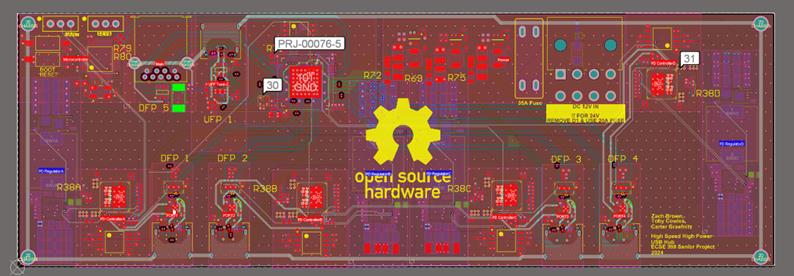
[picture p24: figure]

Figure 4. PCB Layout

We designed our PCB with fabrication in mind, from the very start we researched and chose a CM [contract manufacturer] with the capability to fabricate and assemble our boards, ultimately settling on JLC PCB, a well established player with a good range of capabilities, low prices and quick turnaround times. We made several design decisions to make the manufacturing process as painless as possible. We chose parts that would be available in our CMs parts library and added JLC part numbers to our BoM sheet, additionally we chose our layer stack based on JLCs options settling on the JLC0616H-7628 stack up.


Figure 5. Layer stackup options

We identified this stack up prior to starting our PCB design based on the speed requirements of our design. Our digital traces will see an analog bandwidth of anywhere from 15-25 GHz, which means the design is extremely sensitive to the characteristics of the transmission lines that make up the data traces on the board. Any small inconsistencies in the dielectric constant of the substrate that the copper foil is glued to can cause impedance changes that will negatively affect the signal integrity of the USB3 traces. We selected a 7628 weave for the fiberglass prepreg and core layers of our PCB as it is the most dense and uniform glass weave that JLCPCB, our CM, offers. A 1080 weave would have many small transitions between glass fiber and epoxy that would create changes in the Dk of the transmission line, and thus its impedance, which would then create signal integrity problems due to reflections, radiation, and lower signal strength. We then had the option of the spacing between layers. Changing this spacing influences the required trace width to hit a specific impedance, with a thicker substrate increasing the impedance of a fixed-width trace. We selected the thinnest spacing between our outside layers and their ground planes to best control dissipation in the weave as well as use trace widths that suited our design constraints. Below is the final stackup entered into Altium, which then uses a 2D EM field solver to calculate the required trace widths to achieve our target impedances.


Figure 6. In depth layer stackup

Over the course of this project we made several changes.

Our initial project plan involved using Microchip USB7252C hubs, as they offered internal support for USB-C, eliminating the need for external MUXes. However, this approach had significant drawbacks compared to the final design we adopted. First, the design required two hub ICs, which was not ideal. Second, both the PD controller ICs and the hub ICs needed access to the CC lines, as the hubs relied on these lines for direction detection. This overlap created complications in the design. We addressed these issues by switching to external MUX ICs, which allowed the PD controller IC to manage directionality. This adjustment enabled us to consolidate the design, using a single hub to support all the necessary ports.


Figure 7. Initial Block Diagram

This block diagram went through several additional revisions before we settled on the final version, but these were mostly minor variations.


Figure 8. 3D rendering of PCB layout

Results and Statements of Success:
Criterion 1. | A completed PCB design is produced
Criterion 1.1. | The PCB integrates all target functionality:
This success criteria was met, as we were able to select and integrate ICs for all functionality

Criterion 1.2. The PCB design can be exported as a gerber design for assembly:

This criteria was achieved, all assembly files including GerberX2, BoM and CPL files were exported successfully.

Criterion 2. | The board completes a DRC with no serious violations
Criterion 2.1. | All trace widths are within manufacturer capabilities:
This criteria was successfully met. Traces rules were set according to manufacturer spec and no violations were identified after DRC was ran

Criterion 2.2. All high speed traces meet impedance targets: 2 This criteria was conditionally met. All 90 ohm differential pair traces were within their design rule tolerance, however the

### 50 ohm single ended CC lines raised 40 DRC violations due to

small sections on the top layers were the impedance was 54.8 ohms, however due to the necessity of these narrower traces to interface with the pad on the footprint for the IC, the small length of these sections, and the low speed of the CC lines this was determined to be within tolerance and the violations were waived.

Criterion 2.3. All components do not violate pad to pad or courtyard clearances: This success criteria was conditionally achieved . Altium did not raise any DRC violations however a violating component was later identified during the manufacturing process.

Criterion 2.4. No traces or components violate board edge clearances: This success criteria was achieved successfully.

Criterion 3. | The design passes the manufacturer DFM
Criterion 3.1. | No issues that prevent manufacturability are present in the PCB
routing:
This was achieved successfully, our CM JLC successfully manufactured our PCB without issue.

Criterion 3.2. All components can be assembled successfully by our CM: This was not fully met. Some components were not available in the CM part library due to stock and time issues, additionally we ran into clearance issues not caught by Altium on U6 and C32 pictured below.

2 High speed differential pairs must be perfectly impedance matched to 90 ohms; the single-ended configuration channel signals for USB-C were also impedance matched to 50 ohms.


Figure 9. The component clearance violations between U6A and C32.

We fully completed the design including schematic capture, PCB layout, and routing and this design was able to be exported for manufacturing, meeting success criteria one. Prior to our final export of the design we spent some time doing review and verification. Over the course of our review and verification, DRC identified 95 possible violations. After a manual review of these violations it was determined 40 of these violations are nets in the CC class not meeting the defined rules for their target impedance due to space constraints, and should be able to be safely ignored. 25 of these are net antenna violations caused by TI provided footprints, and can also be ignored. The remaining 20 are small annular rings in the Amphenol provided footprints on the USB C connectors and can also be safely waived. For these reasons we consider criterion 2 to be conditionally met. After working with our contract manufacturer we were able to produce a series of boards successfully, though due to stock issues combined with time constraints and a clearance violation not all components were assembled by our contract manufacturer. For this reason we consider criterion 3 to be partially met.

We have remaining work to do in completing the assembly, bring up, and functional validation of the boards. This is reflected in the functionality success criteria which we were not able to verify this semester.

Our project management this semester started with clear communications between team members. We wrote a project proposal and a project requirement doc to make clear what our goals and deliverables were. We then broke the project into phases which could be entered into Open Project to create a Gantt chart.
We also used less formal methods of project management including a Discord group to help facilitate communication between team members.


Figure 10. Gantt Chart

Budget:
We made early estimations as a ballpark for the budget seen below. This was a cost estimate for 3 units.
Part | Estimate | Note
BOM | 125 | This is per unit. Main IC’s are $62 per unit. Assume an addition $63 per unit for passivies, DrMOS power stages, and any support ICs,
PCBA | 300 | $143 for PCB (5 units) $50 for shipping $100 for PCBA (3 units) NOTE: Due to minimum order quantity PCB and PCBA estimate is for multiple units
Total | 300+125*3=$675 total (3 units) | $225 per unit (for 3 unit)

Table 2. Initial Project Budget

After completing the design and placing the order the final merchandise total came to $636.01 for 5 assembled units. This includes the $78.29 for PCBs, and $520.30 for PCBA, which includes both the BoM and assembly costs. However this does not include the USB C connectors, or fuses, which would add an additional approximately $50, however we are still in line or better then our original budget goals given that we are under $700 for 5 units.

Course | Description
ENGR 210 | Basic circuit and network theory, use of instrumentation
ECSE 245 | More advanced power circuitry,
ECSE 309 | Covers high speed/high frequency signals and the concept of impedance matching
ECSE 344 | More advanced power circuitry
ECSE 371 | Applied circuit design
ECSE 303 | Firmware development

Table 3. Courses upon which our team drew on to complete this project.

[1] A. Rogers, “Configuration of USB7206/USB7206C/USB7216/ USB7216C/USB7252/USB7252C.” Microchip Technology Inc, Nov. 2021. Accessed: Dec. 06, 2024. [Online]. Available: https://ww1.microchip.com/downloads/aemDocuments/documents/UNG/ApplicationNotes/ApplicationNotes/AN2935-Configuration-of-USB7206-USB7206C-USB7216-USB7216C-USB7252-US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 (https://ww1.microchip.com/downloads/aemDocuments/documents/UNG/ApplicationNotes/ApplicationNotes/AN2935-Configuration-of-USB7206-USB7206C-USB7216-USB7216C-USB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)
[2] O. Oji, “ESD and Surge Protection for USB Interfaces Application Note.” Texas Instruments, Jan. 2024. Accessed: Dec. 06, 2024. [Online]. Available: https://www.ti.com/lit/an/slvaf82b/slvaf82b.pdf?ts=1733467824994&ref_url=https%253 A%252F%252Fwww.google.com%252F (https://www.ti.com/lit/an/slvaf82b/slvaf82b.pdf?ts=1733467824994)
[3] “HD3SS3212x Datasheet - Two-Channel Differential 2:1/1:2 USB3.1 Mux/Demux.” Texas Instruments, Sep. 2016. Accessed: Dec. 06, 2024. [Online]. Available: https://www.ti.com/lit/ds/symlink/hd3ss3212.pdf?ts=1733528949874&ref_url=https%25 3A%252F%252Fwww.ti.com%252Fproduct%252FHD3SS3212 (https://www.ti.com/lit/ds/symlink/hd3ss3212.pdf?ts=1733528949874)
[4] “HD3SS3212x Datasheet - Two-Channel Differential 2:1/1:2 USB3.1 Mux/Demux.” Texas Instruments, Sep. 2016. Accessed: Dec. 06, 2024. [Online]. Available: https://www.ti.com/lit/ds/symlink/hd3ss3212.pdf?ts=1733528949874&ref_url=https%25 3A%252F%252Fwww.ti.com%252Fproduct%252FHD3SS3212 (https://www.ti.com/lit/ds/symlink/hd3ss3212.pdf?ts=1733528949874)
[5] “HD3SS3220 Datasheet - USB Type-C DRP Port Controller with SuperSpeed 2:1 MUX.” Texas Instruments, Sep. 2020. Accessed: Dec. 06, 2024. [Online]. Available: https://www.ti.com/lit/ds/symlink/hd3ss3220.pdf?ts=1733475148793&ref_url=https%25 3A%252F%252Fwww.ti.com%252Fproduct%252FHD3SS3220 (https://www.ti.com/lit/ds/symlink/hd3ss3220.pdf?ts=1733475148793)
[6] “High-Speed Layout Guidelines for Signal Conditioners and USB Hubs.” Texas Instruments, Aug. 2018.
[7] “Schematic Checklist for HD3SS3212 and HD3SS3220.” Texas Instruments, Mar. 2021. [Online]. Available:
https://www.ti.com/lit/an/slla481/slla481.pdf?ts=1733530204082&ref_url=https%253A %252F%252Fwww.ti.com%252Fproduct%252FHD3SS3220 (https://www.ti.com/lit/an/slla481/slla481.pdf?ts=1733530204082)
[8] “STM32F070CB STM32F070RB STM32F070C6 STM32F070F6 Datasheet.” STMicroelectronics, Apr. 2024.

[9] “TPS55288 Datasheet - 36-V, 16-A Buck-boost Converter with I2C Interface.” Texas Instruments, Dec. 2020. Accessed: Dec. 06, 2024. [Online]. Available: https://www.ti.com/lit/ds/symlink/tps55288.pdf?ts=1733476430734
[10] H. Chen, “TPS55288 Layout Guideline.” Texas Instruments, Dec. 2020. Accessed: Dec. 06, 2024. [Online]. Available: https://www.ti.com/lit/an/slvaer0b/slvaer0b.pdf?ts=1733528972385&ref_url=https%253 A%252F%252Fwww.ti.com%252Fproduct%252FTPS55288 (https://www.ti.com/lit/an/slvaer0b/slvaer0b.pdf?ts=1733528972385)
[11] “TPS65987D Datasheet - USB Type-C® and USB PD Controller with Integrated Source and Sink Power Path Supporting USB3 and Alternate Mode.” Texas Instruments, Oct. 2022. Accessed: Dec. 06, 2024. [Online]. Available: https://www.ti.com/lit/ds/symlink/tps65987d.pdf?ts=1733468372522&ref_url=https%25 3A%252F%252Fwww.ti.com%252Fproduct%252FTPS65987D (https://www.ti.com/lit/ds/symlink/tps65987d.pdf?ts=1733468372522)
[12] R. Titus, “USB Device Design Checklist.” Microchip Technology Inc, Aug. 2015.
[13] S. Graf, “USB Type C Power Delivery Source with TPS65987D and TPS55288.” Texas Instruments, Apr. 2020. [Online]. Available: https://www.ti.com/lit/ab/slvaeq7/slvaeq7.pdf?ts=1733528979130&ref_url=https%253A %252F%252Fwww.ti.com%252Fproduct%252FTPS55288 (https://www.ti.com/lit/ab/slvaeq7/slvaeq7.pdf?ts=1733528979130)
[14] “USB72x6/USB7252 Silicon Errata and Data Sheet Clarification.” Microchip Technology Inc, Feb. 2022.
[15] “USB7206 Hardware Design Checklist.” Microchip Technology Inc, Dec. 2022. [Online]. Available:
https://ww1.microchip.com/downloads/aemDocuments/documents/UNG/ProductDocuments/DesignChecklist/USB7206-Hardware-Design-Checklist-DS00003336.pdf (https://ww1.microchip.com/downloads/aemDocuments/documents/UNG/ProductDocuments/DesignChecklist/USB7206-Hardware-Design-Checklist-DS00003336.pdf)
[16] “USB7206C Datasheet - 6-Port USB 3.2 Gen 2 Controller Hub.” Microchip Technology Inc, May 2024. Accessed: Dec. 06, 2024. [Online]. Available: https://ww1.microchip.com/downloads/aemDocuments/documents/UNG/ProductDocuments/DataSheets/USB7206C-Data-Sheet-DS00003850.pdf (https://ww1.microchip.com/downloads/aemDocuments/documents/UNG/ProductDocuments/DataSheets/USB7206C-Data-Sheet-DS00003850.pdf)









Drilling

Drill Diameter | 0.15 – 6.3 mm
Hole size Tolerance (Plated) | Through-holes: +0.13 / -0.08 mm Press-fit holes：±0.05 mm
Hole size Tolerance (Non-Plated) | ±0.2mm
Min. Via hole size/diameter | 0.15mm / 0.25mm
Min. Non-plated holes | 0.50mm
Min. Plated Slots | 0.5mm
Min. Non-Plated Slots | 1.0mm
Via Hole-to-Hole Spacing | 0.2mm
Pad Hole-to-Hole Spacing | 0.45mm
Traces
Min. track width and spacing (1 oz) | 0.10 / 0.10 mm
Min. track width and spacing (2 oz) | 0.16 / 0.16 mm
Track width tolerance | ±20%
PTH annular ring | ≧0.20mm
NPTH pad annular ring | ≧0.45mm
Same-net track spacing | 0.25mm
Inner layer via hole to copper clearance | 0.2mm
Inner layer PTH pad hole to copper clearance | 0.3mm
Pad to track clearance | 0.1mm
SMD pad to pad clearance (different nets) | 0.15mm
Via hole to Track | 0.2mm
PTH to Track | 0.28mm min / 0.35mm rec
NPTH to Track | 0.2mm
Soldermask
Soldermask Expansion | 0.038mm
Soldermask bridge | 0.10mm
Solder mask ink thickness | ≥ 10μm

Outline

Routed edges to trace clearance | 0.2mm
Silkscreen
Minimum Line Width | 6 mil (0.153mm)
Minimum text height | 40 mil (1.0mm)
Character width to height ratio | 1:6
Hollow-carved Character width to height ratio | 1:6
Pad To Silkscreen | 0.15mm


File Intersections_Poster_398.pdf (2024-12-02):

speed signals and power.; In order to ensure the project was completed on time we used project

Presented: December 6th, 2024 | Copyright © 2024 | ECSE 398

There is not a commercial USB hub available that is capable of supplying high power USB C PD and high speed data (10Gb/s+) on the same hub. Therefore we propose the design and manufacture of such a hub.
Similar existing solutions are all flawed :
Commercial Solutions
-USB C Hubs (no power)

-USB PD adapters (no data)

-Thunderbolt Docks

(bulky, expensive, unneeded features, limited ports)

Existing Projects

https://github.com/Jana-Marie/PD-Injector
(Clunky, violates USB Spec, but provided assurance that something like this could be done)
1. Limited IC selection. There are few 10gb/s USB hub ICs on the market and none faster Making custom ICs/working with non-public ICs is out of scope of this project so we will be constrained by what is available.
2. Routing traces and manufacturing boards for high frequency data gets more difficult the higher the data speed, which could limit the CMs we can work with as well as impose limits on the design tools required.
3. Troubleshooting data lines may be difficult given that it would require an oscilloscope fast enough to keep up with a 10 Gb/s data speed.

FCC Radio Devices Rule on Homebuilt Devices, 47 C.F.R § 15.23, 2021. [Online] Available: https://ecfr.federalregister.gov/current/title-47/chapter-I/subchapter-A/part-15. Accessed May 12, 2021.

Universal Serial Bus 3.2 Revision 1.1 Specification, USB-IF, USB 3.0 Promoter Group, June 2022. [Online]. Available: https://usb.org/document-library/usb-32-revision-11-june-2022 (https://usb.org/document-library/usb-32-revision-11-june-2022)

USB Power Delivery Specification Revision 3.2, Version 1.0, USB-IF, Oct. 2023. [Online]. Available: https://usb.org/document-library/usbpower-delivery (https://usb.org/document-library/usb-power-delivery)
USB Type-C Cable and Connector Specification Release 2.3, USB-IF, Oct. 2023. [Online]. Available: https://usb.org/document-library/usb-type-

cr-cable-and-connector-specification-release-23 (https://usb.org/document-library/usb-type-cr-cable-and-connector-specification-release-23)

I

2C-bus specification and user manual, UM10204, NXP Semiconductors, Oct. 2021. [Online]. Available: https://www.nxp.com/docs/en/user-

guide/UM10204.pdf (https://www.nxp.com/docs/en/user-guide/UM10204.pdf)
IPC, IPC-2141: Controlled Impedance Circuit Boards and High Speed Logic Design (IPC-2141A), Revision A. IPC, 2004.
Course | Description
ENGR 210 | Basic circuit and network theory, use of instrumentation
ECSE 245 | More advanced power circuitry
ECSE 309 | Covers high speed/high frequency signals. Impedance matching
ECSE 344 | More advanced power circuitry
ECSE 371 | Applied circuit design
ECSE 303 | Firmware development

Schematic Capture was
completed in Altium
Designer.
We used a multi-sheet
layout and sheet
symbols to make the
project efficient

We laid out the board as a 6 layer board. We kept the high-speed signals on the outer layers to prioritize signal integrity and avoid issues with punch through. Each outer layer has a ground plane underneath it. The two inner layers are used for low-

In order to verify our board we ran DRC on the design.
DRC identified 95 possible violations.
After review it was determined 40 of these violations are nets in the CC class not meeting the defined rules for their target impedance due to space constraints, and should be able to be safely ignored.
25 of these are net antenna violations caused by TI provided footprints, and can also be ignored. The remaining 20 are small anular rings in the amphenol provided pads on the USB C connectors and can also be safely waived.

management strategies to divide and plan out the work including a detailed project plan document and a Gantt Chart. We also did multiple design reviews throughout.

We designed our board with manufacturability in mind. Early on in the design process we identified our target CM [contract manufacturer] JLC PCB. We chose JLC due to their extensive part library, competitive capabilities, fast turn times and low prices. We defined our board layer stack based on
the JLC0616H-7628 stack up to meet our impedance requirements. All our parts included the JLC part number for ease of ordering.

Thank you to Altium for providing student licenses. Thank you to Dr.Lee for being our advisor and his lab for supporting this project financially.

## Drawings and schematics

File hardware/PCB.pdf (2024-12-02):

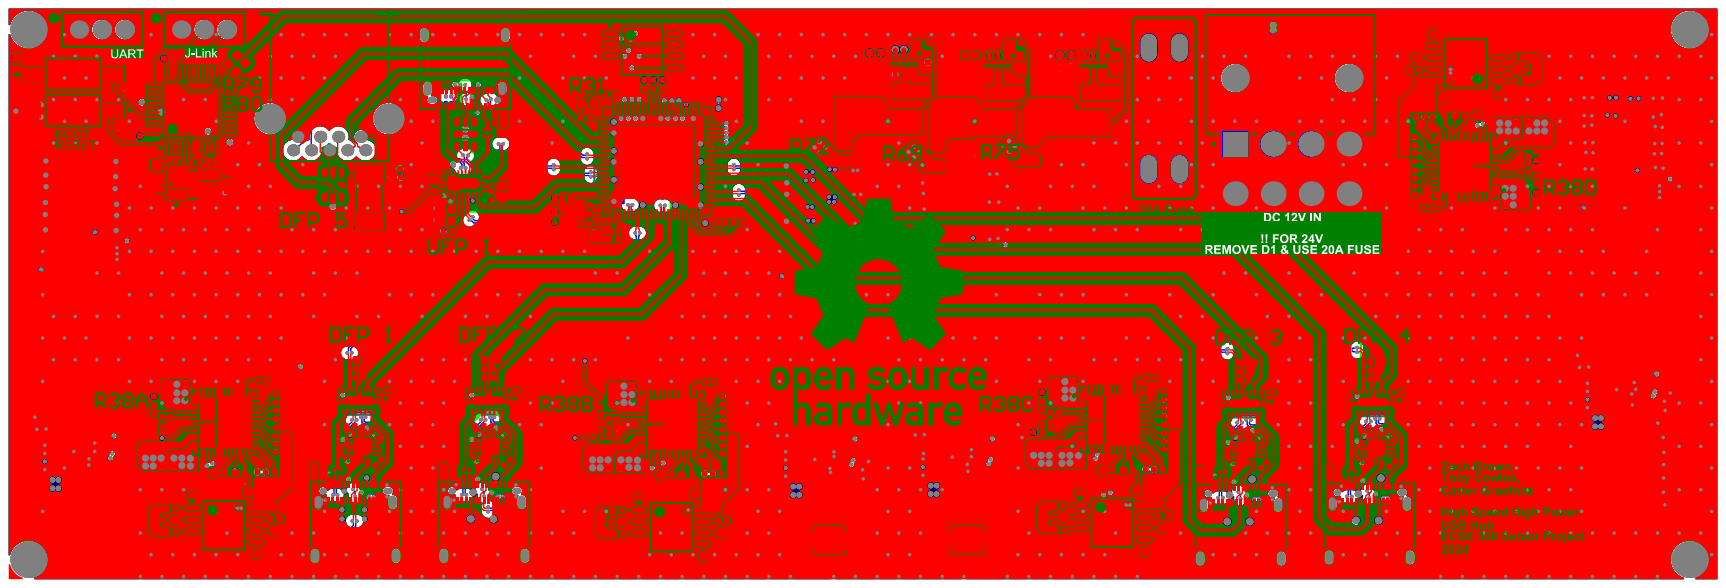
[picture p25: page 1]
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

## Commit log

2024-08-27 Create KiCad project. Import USB7250p
    [USB_C_PD_HUB.kicad_pcb, USB_C_PD_HUB.kicad_sch]
2024-08-27 Sch stuff
    [Hub_IC.sch.kicad_sch, Power.kicad_sch, ports.kicad_sch]
2024-12-02 Add Stuff
    [Hub_IC.sch.kicad_sch, Power.kicad_sch, USB_C_PD_HUB.kicad_pcb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]
